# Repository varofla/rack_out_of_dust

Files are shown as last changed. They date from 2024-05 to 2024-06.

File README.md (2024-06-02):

# Rack Out of Dust 프로젝트

> 치사하게 너만 공기청정기 쓰냐? 서버도 공기청정기 쓸 자격 있다!!
> 

24/7 중노동을 하는 홈랩 서버에게 인권..아니 서권을 마련해주는 프로젝트입니다.



# 구성

- SoC: nRF52840
    - nRF Connect SDK
    - IEEE 802.15.4 (ZigBee)
- 센서
    - 쿨링팬 타코미터 (RPM)
    - PMS7003 미세먼지 센서
    - SHT45 온습도 센서
- 쿨링팬: Noctua NF-F12 industrialPPC-300
- 연동: Zigbee2MQTT → Home Assistant
- 전원: 12 V 어댑터

# 파일

```bash
├── fw : 펌웨어 (nRF Connect SDK)
├── hw
│   ├── 3D printed : 3D 프린팅 외형 파일
│   └── PCB : PCB 거버파일 및 JLCPCB SMT 파일 (v1는 잘못 설계된 파일로, v2 사용
└── sw : Z2M 커스텀 장치 정의 파일
```

# 관련 포스팅

1. [프로젝트 설계](https://www.varofla.com/475c7271-f304-468b-922f-4c4ca632acf4)
2. [외형 설계 및 제작](https://www.varofla.com/e27d810e-9beb-4bba-b57b-e6c40fa9b2bd)
3. [펌웨어 구현 및 Z2M 연결](https://www.varofla.com/62771ae1-a312-4e24-9179-140e787831f7)
4. [PCB 설계 및 최종 조립 (완성)](https://www.varofla.com/93159dcd-b3e2-4ca6-9c15-6a3c6facd333)

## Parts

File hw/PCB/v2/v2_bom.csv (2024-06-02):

Comment | Designator | Footprint | LCSC Part #
0.5p | C6 | 0402_CAP | C76912
0.8p | C5 | 0402_CAP | C76915
1k | R7 | 0402_RES | C11702
1k | R9 | R0603 | C4109
1k | R10 | 0402_RES | C11702
1u | C11 C12 | CAPC1608X85 | C15849
2k | R3 | 0402_RES | C4109
2k | R8 | R0603 | C25890
4.7n | L1 | INDC1006X60N | C395070
4.7u | C4 | CAPC1608X85 | C19666
10k | R2 R4 R5 R6 | 0402_RES | C25744
10n | C16 C21 | 0402_CAP | C15195
10u | C19 C22 | CAPC1608X85 | C96446
12p | C8 C9 | 0402_CAP | C1547
13.7k | R1 | 0402_RES | C321298
18u | L2 | INDUCTOR_6X6MM_TDK_VLC6045 | C96939
22u | C18 | CAPC3216X135 | C12891
32MHz | U$1 | BT-XTAL_2016_N | C2965582
47u | C17 | CAPC3216X135 | C96123
100n | C1 C2 C3 C10 C14 C15 C20 C23 C25 C28 | 0402_CAP | C1525
100p | C13 | 0402_CAP | C1546
AMS1117 | U2 | SOT229P700X180-4N | C6186
GREEN | D3 | LED-0603 | C965804
NRF52840-QIAA-R | IC1 | NRF52840-QIAA | C190794
PMS7003 | U3 | PMS7003 | C3975131
SHT45-AD1B-R3 | U$2 | SHT4X | C5221601
SS14F | D4 | SODFL3617X108N | C7420316
TPS54331DR | U1 | SOIC127P599X175-8N | C9865
TS-1088-AR02016 | U$3 U$5 | TS-1088-AR02016 | C720477
WHITE | D2 | LED-0603 | C2290
U$4 | U$4 | U$4 | C395849
J1 | J1 | J1 | C240840
J4 | J4 | J4 | C2937625
J2 | J2 | J2 | C2937625

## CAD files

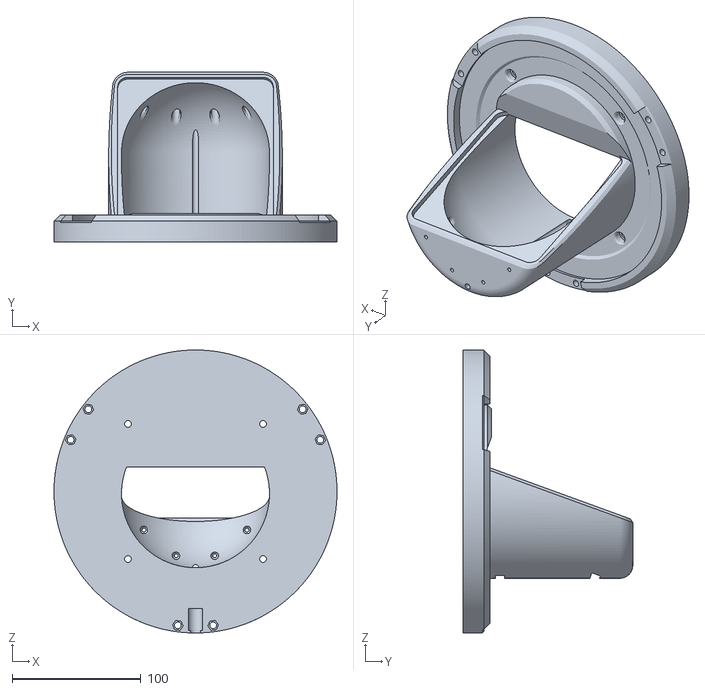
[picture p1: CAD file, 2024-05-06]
hw/3D printed/body.stl
220.0 x 131.9 x 220.0

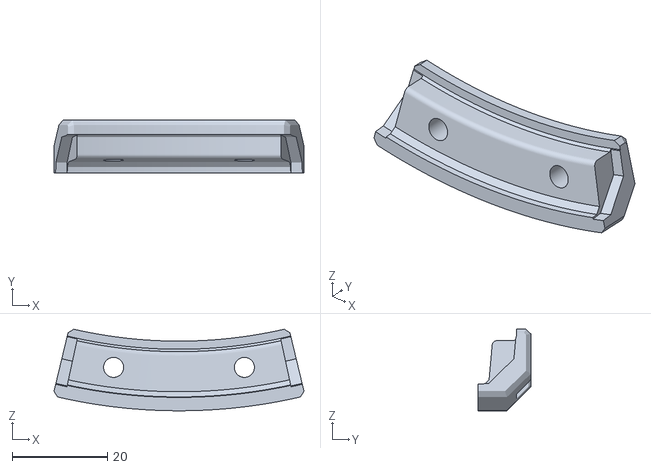
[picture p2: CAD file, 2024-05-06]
hw/3D printed/jaw.stl
52.4 x 11.0 x 17.1

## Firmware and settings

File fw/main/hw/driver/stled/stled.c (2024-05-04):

#include <stdint.h>

#include <zephyr/device.h>
#include <zephyr/drivers/pwm.h>
#include <zephyr/kernel.h>
#include <zephyr/logging/log.h>

#include "stled.h"

LOG_MODULE_REGISTER(stled, LOG_LEVEL_INF);

typedef struct {
  bool is_init;

  k_tid_t thread_id;
  struct k_thread thread_data;

  stled_pattern_t current_pattern;

  bool is_brightness_increasing;
  uint16_t last_brightness;
} module_data_t;
static module_data_t module_data;

static const struct pwm_dt_spec s_stled_dt = PWM_DT_SPEC_GET(DT_ALIAS(stled));

K_THREAD_STACK_DEFINE(s_stled_stack_area, 300);

#define PWM_PERIOD_25KHZ PWM_KHZ(25) // fan4p와 같은 pwm0을 사용하기 때문에 주파수 맞춰줌

#define DELAY_SLOW_US 1500
#define DELAY_MEDIUM_US 500
#define DELAY_FAST_US 100

/**
 * @brief 밝기 설정
 *
 * @param power 밝기 (0~1000)
 */
void s_set_brightness(uint16_t power) {
  uint32_t speed = (PWM_PERIOD_25KHZ * power) / 1000;
  speed = speed > PWM_PERIOD_25KHZ ? PWM_PERIOD_25KHZ : speed;

  pwm_set_pulse_dt(&s_stled_dt, speed);
}

static void s_change_brightness_target(void) {
  if (module_data.last_brightness == 1000) {
    module_data.is_brightness_increasing = false;
  } else if (module_data.last_brightness == 0) {
    module_data.is_brightness_increasing = true;
  }

  switch (module_data.current_pattern) {
  case STLED_PATTERN_BLINK_SLOW:
  case STLED_PATTERN_BLINK_MEDIUM:
  case STLED_PATTERN_BLINK_FAST:
    module_data.last_brightness = module_data.is_brightness_increasing ? 1000 : 0;
    break;

  case STLED_PATTERN_BREATH_SLOW:
  case STLED_PATTERN_BREATH_MEDIUM:
  case STLED_PATTERN_BREATH_FAST:
    module_data.last_brightness += module_data.is_brightness_increasing ? 1 : -1;
    break;

  default:
    break;
  }

  s_set_brightness(module_data.last_brightness);
}

static void s_thread_sleep(void) {
  switch (module_data.current_pattern) {
  case STLED_PATTERN_BLINK_SLOW:
    k_usleep(DELAY_SLOW_US * 2000);
    break;
  case STLED_PATTERN_BLINK_MEDIUM:
    k_usleep(DELAY_MEDIUM_US * 2000);
    break;
  case STLED_PATTERN_BLINK_FAST:
    k_usleep(DELAY_FAST_US * 2000);
    break;

  case STLED_PATTERN_BREATH_SLOW:
    k_usleep(DELAY_SLOW_US);
    break;
  case STLED_PATTERN_BREATH_MEDIUM:
    k_usleep(DELAY_MEDIUM_US);
    break;
  case STLED_PATTERN_BREATH_FAST:
    k_usleep(DELAY_FAST_US);
    break;

  default:
    break;
  }
}

static void s_stled_thread(void *, void *, void *) {
  for (;;) {
    s_change_brightness_target();

    s_thread_sleep();
  }
}

bool stled_init(void) {
  if (!pwm_is_ready_dt(&s_stled_dt)) {
    LOG_ERR("Error: PWM device %s is not ready", s_stled_dt.dev->name);
    return false;
  }

  pwm_set_dt(&s_stled_dt, PWM_PERIOD_25KHZ, 0);

  stled_set(STLED_PATTERN_OFF);

  module_data.is_init = true;

  return true;
}

/**
 * @brief 심신삐약상태에서 작성함. 문제 있을수도 있음. 아니 문제있을듯;;;
 *
 * @param pattern
 * @return true
 * @return false
 */
bool stled_set(stled_pattern_t pattern) {
  if (!module_data.is_init) {
    return false;
  }

  module_data.current_pattern = pattern;
  if (pattern == STLED_PATTERN_ON ||
      pattern == STLED_PATTERN_OFF) {
    if (module_data.thread_id != 0) {
      k_thread_abort(module_data.thread_id);
      module_data.thread_id = 0;
    }
    s_set_brightness(pattern ? 1000 : 0);
  } else if (module_data.thread_id == 0) {
    module_data.thread_id = k_thread_create(&module_data.thread_data, s_stled_stack_area,
                                            K_THREAD_STACK_SIZEOF(s_stled_stack_area),
                                            s_stled_thread,
                                            NULL, NULL, NULL,
                                            5, 0, K_NO_WAIT);
  }

  return true;
}

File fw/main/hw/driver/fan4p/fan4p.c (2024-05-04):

#include <zephyr/kernel.h>

#include <zephyr/device.h>

#include <zephyr/drivers/gpio.h>
#include <zephyr/drivers/pwm.h>

#include <zephyr/sys/printk.h>

#include "fan4p.h"

#define PWM_PERIOD_25KHZ PWM_KHZ(25)
#define SPEED_FEEDBACK_TIMEOUT_SEC 1

typedef struct {
  struct k_timer feedback_timeout_timer;

  struct gpio_callback feedback_gpio_cb_data;
  uint32_t feedback_last_tick;

  uint16_t rpm;

} module_data_t;
static module_data_t module_data;

#define ZEPHYR_USER_NODE DT_PATH(zephyr_user)
static const struct gpio_dt_spec s_speed_feedback_gpio_dt = GPIO_DT_SPEC_GET(ZEPHYR_USER_NODE, fan4p_speed_feedback_gpios);
static const struct pwm_dt_spec s_pwm_dt = PWM_DT_SPEC_GET(DT_PATH(zephyr_user));

// TODO: PWM capture 에라이 왜 이제봤지
// https://docs.zephyrproject.org/latest/hardware/peripherals/pwm.html#c.pwm_enable_capture
static void s_speed_feedback_callback(const struct device *dev, struct gpio_callback *cb, uint32_t pins) {
  uint32_t curr_tick = k_cycle_get_32();
  double period = (double)(curr_tick - module_data.feedback_last_tick) / sys_clock_hw_cycles_per_sec();
  module_data.feedback_last_tick = curr_tick;

  module_data.rpm = (1 / period) / 2 * 60;
}

void s_speed_timeout_timer_function(struct k_timer *timer_id) {
  if ((k_cycle_get_32() - module_data.feedback_last_tick) / sys_clock_hw_cycles_per_sec() >= SPEED_FEEDBACK_TIMEOUT_SEC) {
    module_data.rpm = 0;
  }
}

bool fan4p_init(void) {
  bool ret = true;

  k_timer_init(&module_data.feedback_timeout_timer, s_speed_timeout_timer_function, NULL);
  k_timer_start(&module_data.feedback_timeout_timer, K_SECONDS(1), K_SECONDS(1));

  ret &= gpio_pin_interrupt_configure_dt(&s_speed_feedback_gpio_dt, GPIO_INT_EDGE_TO_ACTIVE) == 0;
  gpio_init_callback(&module_data.feedback_gpio_cb_data, s_speed_feedback_callback, BIT(s_speed_feedback_gpio_dt.pin));
  ret &= gpio_add_callback_dt(&s_speed_feedback_gpio_dt, &module_data.feedback_gpio_cb_data) == 0;

  ret &= fan4p_set_power(0) == true;

  if (ret != true) {
    printk("fan4p init error!!");
  }

  return ret;
}

/**
 * @brief 속도 설정
 *
 * @param power 0~100
 * @return true
 * @return false
 */
bool fan4p_set_power(uint8_t power) {
  uint32_t speed = (PWM_PERIOD_25KHZ * power) / 100;
  speed = speed > PWM_PERIOD_25KHZ ? PWM_PERIOD_25KHZ : speed;

  return pwm_set_pulse_dt(&s_pwm_dt, speed) == 0;
}

/**
 * @brief 속도 출력
 *
 * @return uint16_t
 */
uint16_t fan4p_get_rpm(void) {
  return module_data.rpm;
}

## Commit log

2024-05-04 macOS, VSCode 추가
2024-05-04 build 추가
2024-05-06 3D 프린팅 파일 추가
    [body.stl, jaw.stl]
2024-05-06 PCB 제작 파일 추가
    [PCB v68_top_bom.csv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]
2024-06-02 V2 PCB 추가
    [v1_bom.csv, v2_bom.csv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]
2024-06-02 .vscode 추가
2024-06-02 V2 PCB 디바이스트리 반영
2024-06-02 SHT45 드라이버 추가
2024-06-02 온도센서 변경 (AM2320 -> SHT45)
2024-06-02 ZigBee 모델 ID tset 제거
2024-06-02 Z2M 커스텀 장치 파일 추가
2024-06-02 README 추가
2024-06-02 사진 추가
